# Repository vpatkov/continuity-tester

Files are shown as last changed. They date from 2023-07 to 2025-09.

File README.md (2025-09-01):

# Continuity Tester

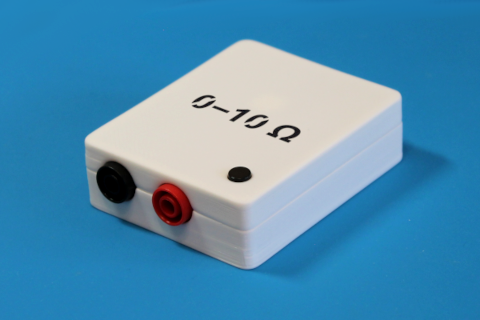
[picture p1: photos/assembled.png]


Ultra low-voltage and fast continuity tester. Digital multimeters are very good
at precise measurements but usually not so good at continuity testing. This
little tester solves the problem.

- **Open terminals voltage is 100 mV, short terminals current is 100 μA.**
  Suitable for in-circuit testing (keep p-n junctions closed) without the
  risk of damaging sensitive components. DMMs usually apply several volts or
  milliamps to the terminals (and not always specified).

- **Resistance-dependent beeper tones with chromatic steps.**
  Allows you to differentiate resistance by ear without moving your viewpoint.
  The range is 0–10 Ω with 1 Ω steps. DMMs usually have a pretty big threshold
  and require you to look at the screen to read the resistance, e.g. if you
  want to catch a bad connection.

- **Detects shorts of 1 ms with an ensured minimal beep duration of 100 ms.**
  Suitable for finding connections by sweeping and brushing without the risk
  of missing a beep. Gold-plated probes are recommended.

- **Auto-hold the minimal resistance.**
  Helps against unstable contacts, e.g. on dirty, oxidized, or lacquered
  boards. The hold resets when the resistance becomes greater than 10 Ω.

- **200 working hours on a single CR2032 cell.**
  Consumes 0.7 mA when on (+0.3 mA when beeping), 0.1 μA when off. After 3
  minutes of inactivity the tester switched off automatically.

- **±30 V input protection.**
  The tester should not be used on a powered circuit, but just in case.
  Also saves against charged capacitors. The input impedance of the tester is
  1 kΩ, so the risk of damaging an accidentally powered circuit under test is
  also low.



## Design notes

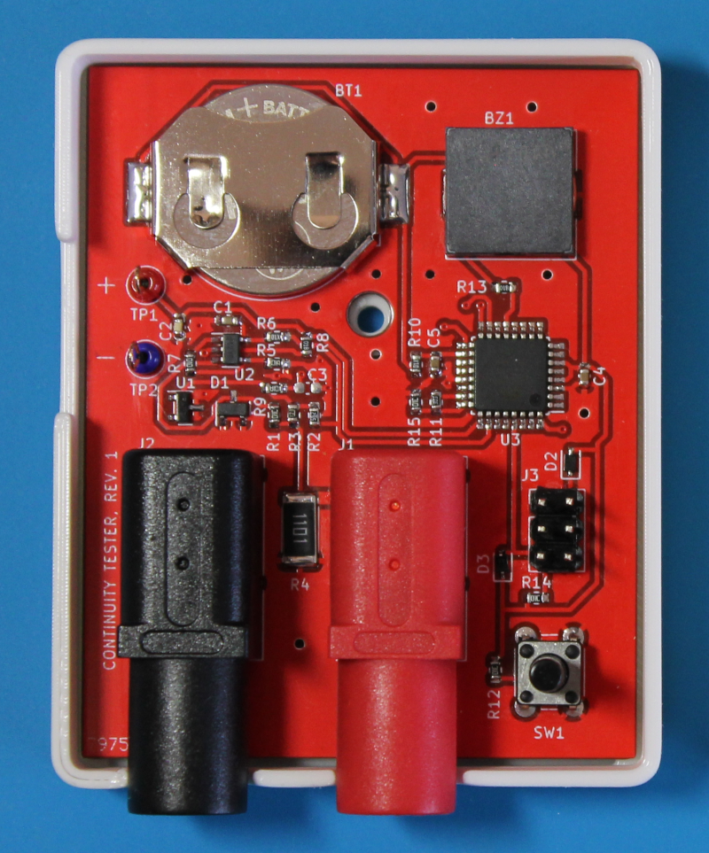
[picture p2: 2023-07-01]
photos/open.png

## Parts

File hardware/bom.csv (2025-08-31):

Reference | Qty | Value | Footprint | Note
BT1 | 1 | CR2032 | Battery:BatteryHolder_MPD_BC2003_1x2032
BZ1 | 1 | PKLCS1212E4001 | Buzzer_Beeper:Buzzer_Murata_PKLCS1212E
C1,C4,C5 | 3 | 100n | Capacitor_SMD:C_0603_1608Metric
C2 | 1 | 1n | Capacitor_SMD:C_0603_1608Metric
D1 | 1 | BAV99 | Package_TO_SOT_SMD:SOT-23
D2 | 1 | BAT54J | Diode_SMD:D_SOD-323F
D3 | 1 | BAS316 | Diode_SMD:D_SOD-323
J1,J2 | 2 | Banana | Connector:Banana_Cliff_FCR7350x_S16N-PC_Horizontal
J3 | 1 | Pin Header Male | Connector_PinHeader_2.54mm:PinHeader_2x03_P2.54mm_Vertical
Q1 | 1 | AO3423 | Package_TO_SOT_SMD:SOT-23
R1,R12,R14 | 3 | 10k | Resistor_SMD:R_0603_1608Metric
R2 | 1 | 6.2k | Resistor_SMD:R_0603_1608Metric
R3 | 1 | 12.4k | Resistor_SMD:R_0603_1608Metric | 1%
R4 | 1 | 1.1k | Resistor_SMD:R_2512_6332Metric | 1% 1W
R5 | 1 | 1k | Resistor_SMD:R_0603_1608Metric | 1%
R6,R10 | 2 | 10 | Resistor_SMD:R_0603_1608Metric
R7 | 1 | 1M | Resistor_SMD:R_0603_1608Metric | 1%
R8,R13 | 2 | 1k | Resistor_SMD:R_0603_1608Metric
R9 | 1 | 100 | Resistor_SMD:R_0603_1608Metric
R11 | 1 | 30k | Resistor_SMD:R_0603_1608Metric | 1%
R15 | 1 | 10k | Resistor_SMD:R_0603_1608Metric | 1%
SW1 | 1 | Tactile Button | Button_Switch_THT:SW_PUSH_6mm | Height 15mm
TP1,TP2 | 2 | TestPoint | TestPoint:TestPoint_Loop_D3.50mm_Drill0.9mm_Beaded
U1 | 1 | TLV431 | Package_TO_SOT_SMD:SOT-23
U2 | 1 | MCP6V61 | Package_TO_SOT_SMD:SOT-23-5
U3 | 1 | ATmega88PA-A | Package_QFP:TQFP-32_7x7mm_P0.8mm

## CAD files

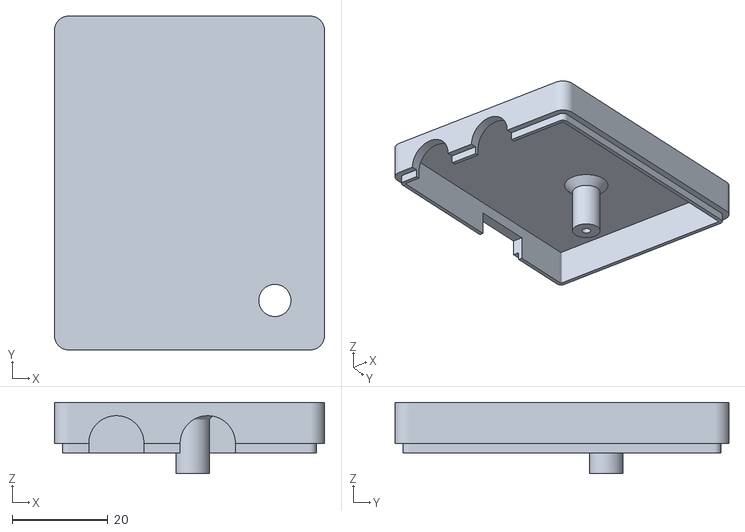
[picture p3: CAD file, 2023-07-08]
case/top.stl
56.3 x 69.6 x 14.8

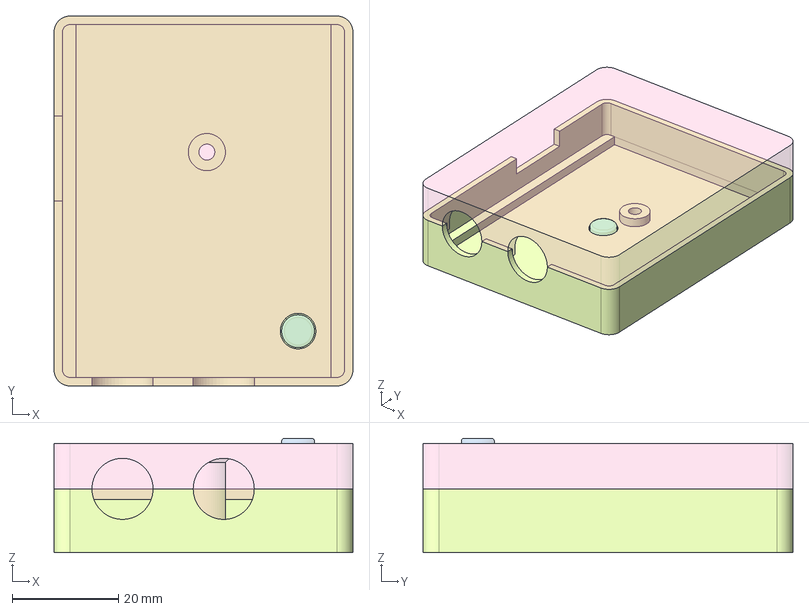
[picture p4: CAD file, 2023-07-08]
case/case.FCStd
56.3 x 69.6 x 21.5 mm
bottom
top
cap

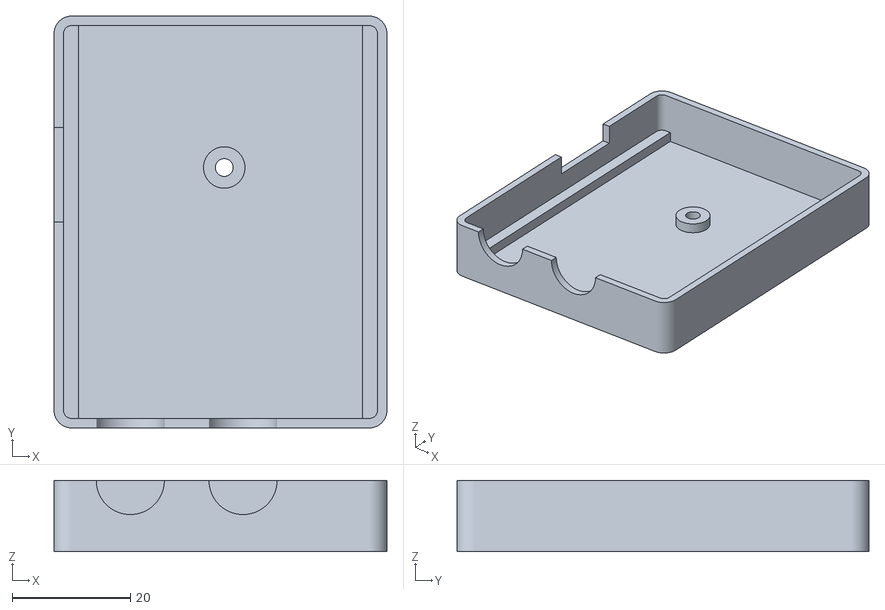
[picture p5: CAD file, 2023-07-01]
case/bottom.stl
56.3 x 69.6 x 12.0

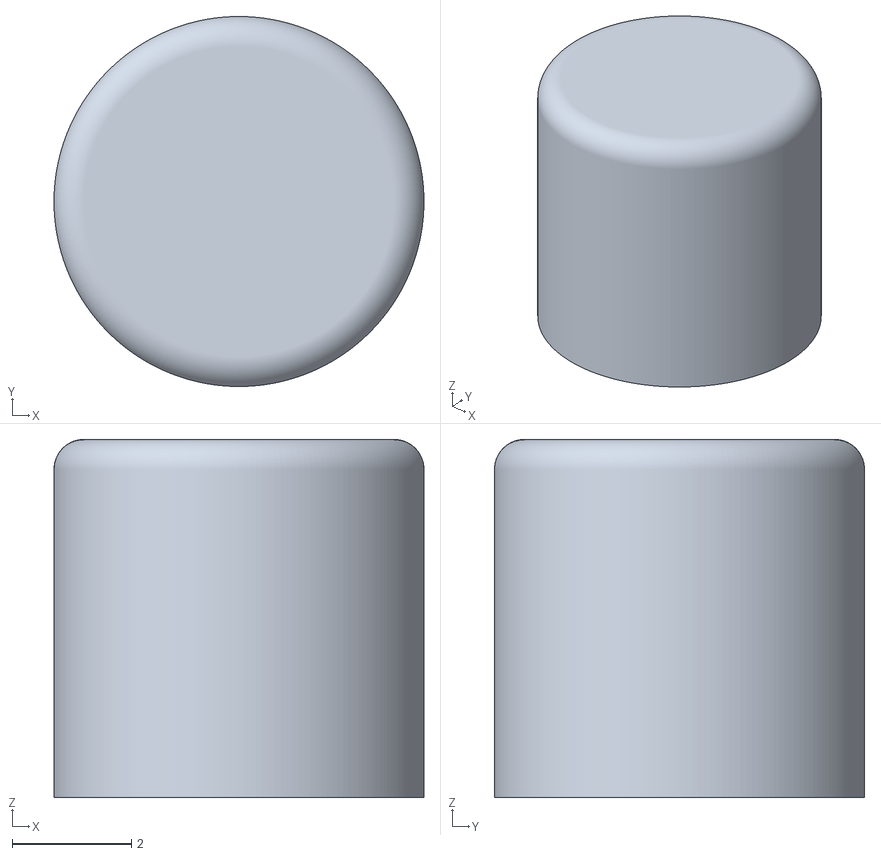
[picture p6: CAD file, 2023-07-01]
case/cap.stl
6.20 x 6.20 x 6.00

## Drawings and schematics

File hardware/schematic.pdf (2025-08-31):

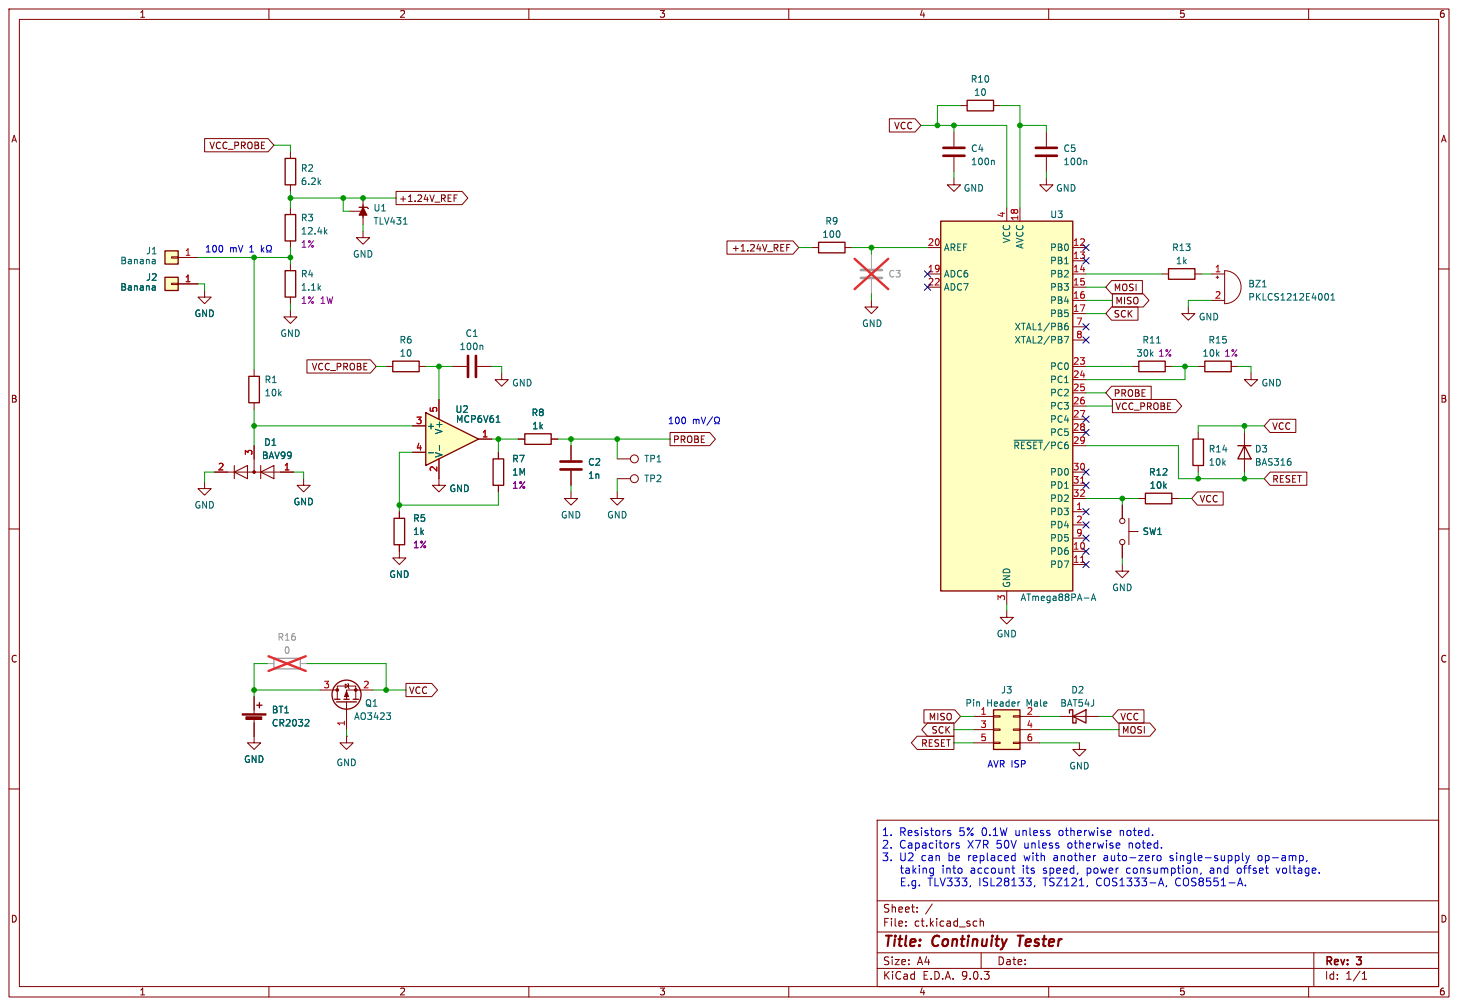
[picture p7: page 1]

Id: 1/1 Title: Continuity Tester File: ct.kicad_sch Sheet: /

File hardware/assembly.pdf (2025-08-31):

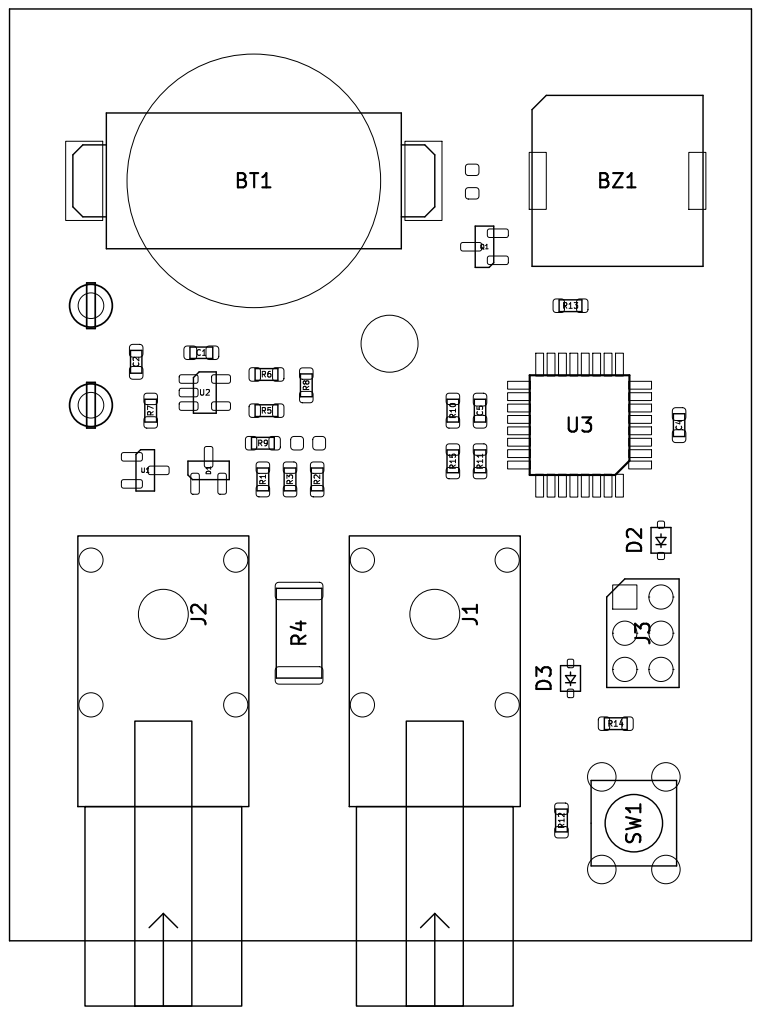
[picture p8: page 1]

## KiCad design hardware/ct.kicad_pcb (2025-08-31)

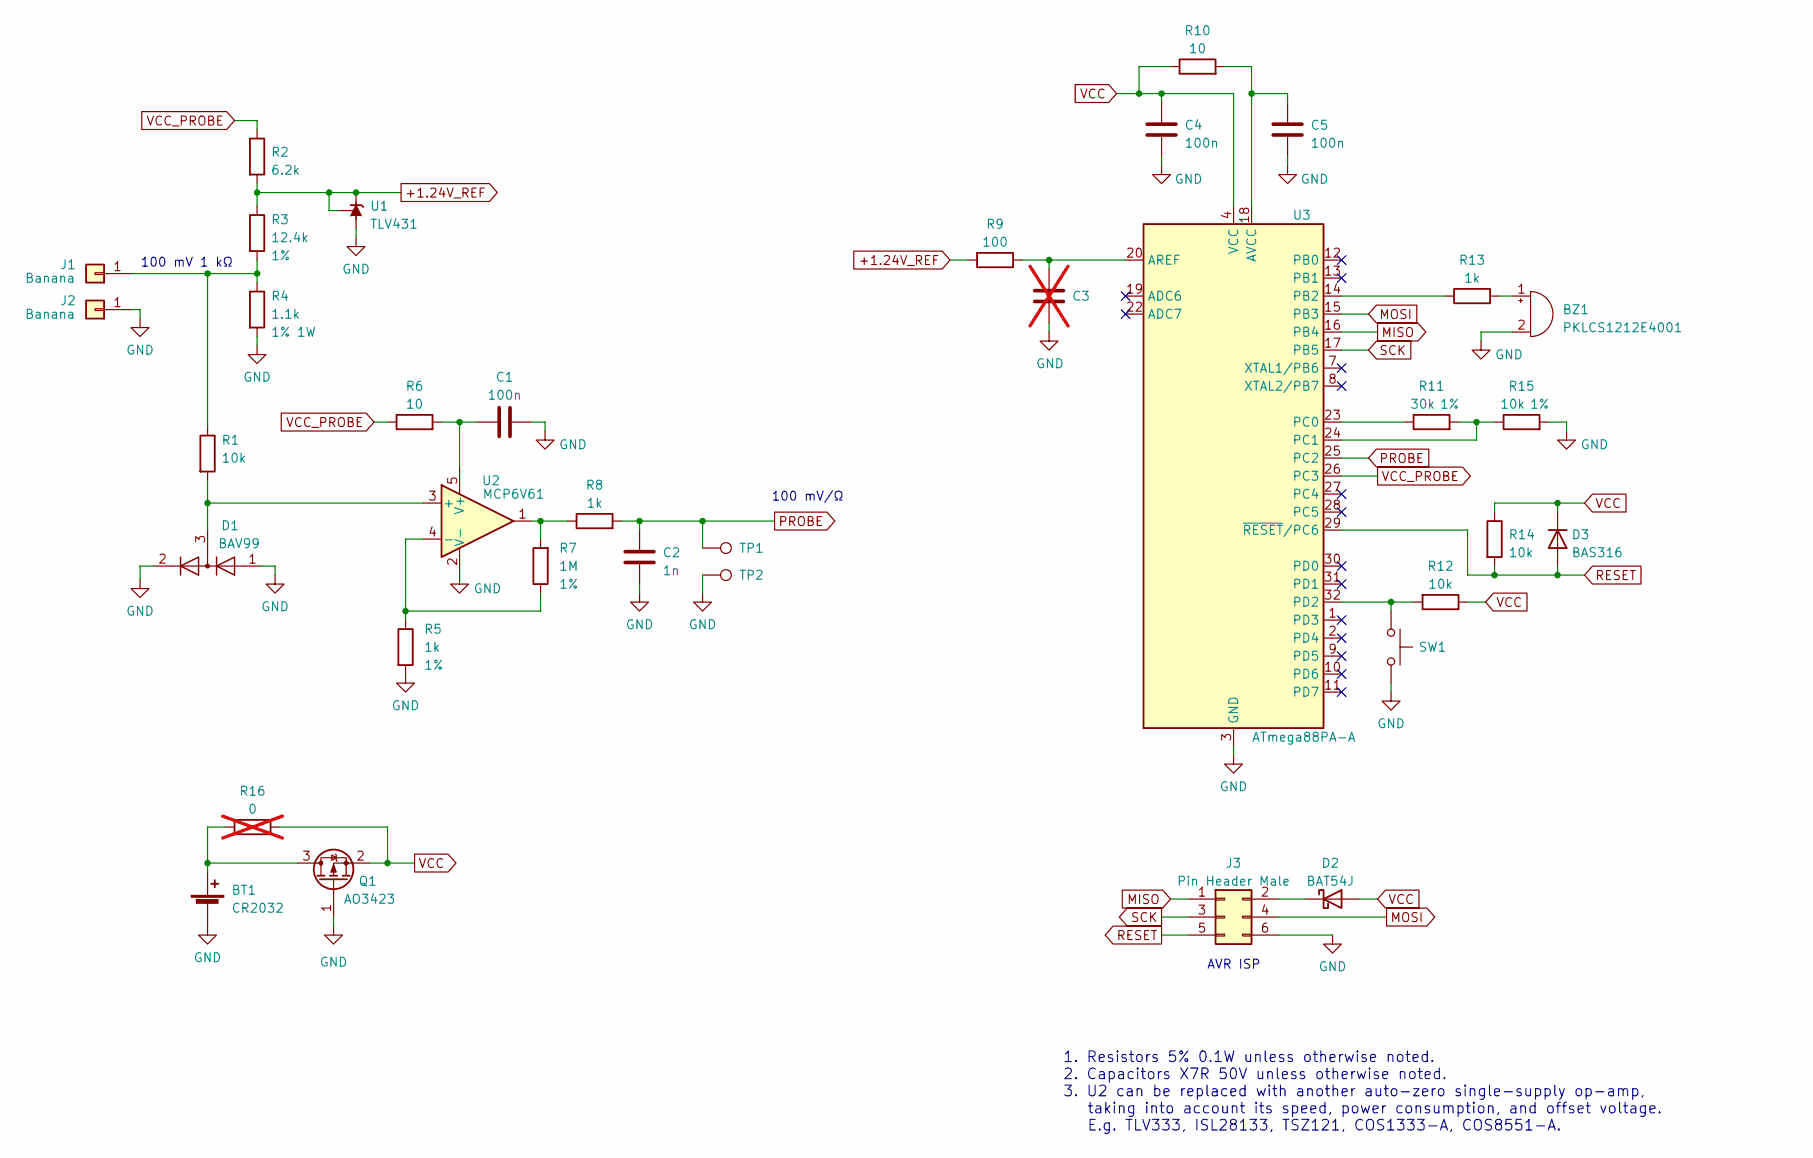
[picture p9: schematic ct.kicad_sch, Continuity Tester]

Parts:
BT1: CR2032; BatteryHolder_MPD_BC2003_1x2032
BZ1: PKLCS1212E4001; Buzzer_Murata_PKLCS1212E
C1, C4, C5: 100n; C_0603_1608Metric
C2: 1n; C_0603_1608Metric
C3: C_0603_1608Metric; not fitted
D1: BAV99; SOT-23
D2: BAT54J; D_SOD-323F
D3: BAS316; D_SOD-323
J1, J2: Banana; Banana_Cliff_FCR7350x_S16N-PC_Horizontal
J3: Pin Header Male; PinHeader_2x03_P2.54mm_Vertical
Q1: AO3423; SOT-23
R1, R12, R14, R15: 10k; R_0603_1608Metric
R2: 6.2k; R_0603_1608Metric
R3: 12.4k; R_0603_1608Metric
R4: 1.1k; R_2512_6332Metric
R5, R8, R13: 1k; R_0603_1608Metric
R6, R10: 10; R_0603_1608Metric
R7: 1M; R_0603_1608Metric
R9: 100; R_0603_1608Metric
R11: 30k; R_0603_1608Metric
R16: 0; R_0603_1608Metric; not fitted
SW1: Tactile Button; SW_PUSH_6mm
TP1, TP2: TestPoint; TestPoint_Loop_D3.50mm_Drill0.9mm_Beaded
U1: TLV431; SOT-23
U2: MCP6V61; SOT-23-5
U3: ATmega88PA-A; TQFP-32_7x7mm_P0.8mm

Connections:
+1.24V_REF: R2.2, R3.1, R9.2, U1.1 (K), U1.2 (REF)
GND: BT1.2 (-), BZ1.2 (+), C1.2, C2.2, C3.2, C4.2, C5.2, D1.1 (K), D1.2 (A), J2.1, J3.6, Q1.1 (G), R4.2, R5.2, R15.2, SW1.2, TP2.1, U1.3 (A), U2.2 (V-), U3.3 (GND), U3.5 (GND), U3.21 (GND)
MISO: J3.1, U3.16 (PB4)
MOSI: J3.4, U3.15 (PB3)
unnamed: BT1.1 (+), Q1.3 (D), R16.1
unnamed: BZ1.1 (-), R13.2
unnamed: D2.1 (K), J3.2
unnamed: J1.1, R1.1, R3.2, R4.1
unnamed: R7.2, R8.1, U2.1
unnamed: D1.3 (K), R1.2, U2.3 (+)
unnamed: R5.1, R7.1, U2.4 (-)
unnamed: C1.1, R6.2, U2.5 (V+)
unnamed: C3.1, R9.1, U3.20 (AREF)
unnamed: C5.1, R10.2, U3.18 (AVCC)
unnamed: R13.1, U3.14 (PB2)
unnamed: R11.1, U3.23 (PC0)
unnamed: R11.2, R15.1, U3.24 (PC1)
unnamed: R12.2, SW1.1, U3.32 (PD2)
PROBE: C2.1, R8.2, TP1.1, U3.25 (PC2)
RESET: D3.2 (A), J3.5, R14.2, U3.29 (~RESET/PC6)
SCK: J3.3, U3.17 (PB5)
VCC: C4.1, D2.2 (A), D3.1 (K), Q1.2 (S), R10.1, R12.1, R14.1, R16.2, U3.4 (VCC), U3.6 (VCC)
VCC_PROBE: R2.1, R6.1, U3.26 (PC3)

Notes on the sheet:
100 mV/Ω
AVR ISP
1. Resistors 5% 0.1W unless otherwise noted. 2. Capacitors X7R 50V unless otherwise noted. 3. U2 can be replaced with another auto-zero single-supply op-amp, taking into account its speed, power consumption, and offset voltage. E.g. TLV333, ISL28133, TSZ121, COS1333-A, COS8551-A.
100 mV 1 kΩ

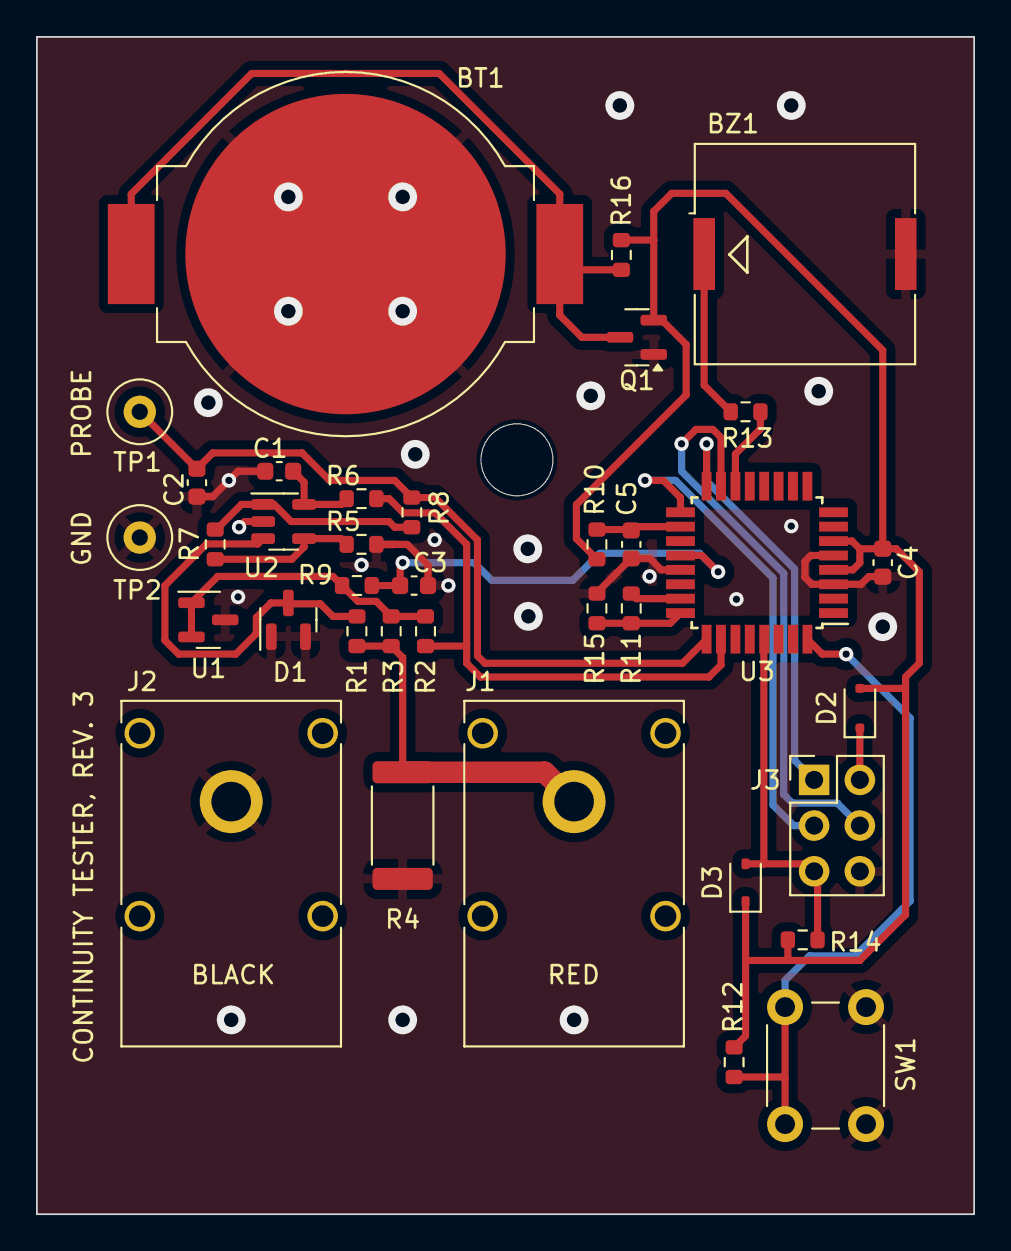
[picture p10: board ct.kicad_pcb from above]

Board: 2 copper layers, 52.1 x 65.4 mm, 36 parts (0 on the bottom side), 23 nets.

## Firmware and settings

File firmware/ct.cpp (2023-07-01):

/* Main program */

#include <stdint.h>
#include <avr/io.h>
#include <avr/pgmspace.h>
#include <avr/sleep.h>
#include "common.hpp"
#include "delay.hpp"
#include "gpio.hpp"
#include "tones.hpp"
#include "volatile.hpp"

/* Peripherals are configured for 1 MHz system clock */
static_assert(F_CPU == 1e6, "");

constexpr Gpio::Pin beeper = Gpio::B2;
constexpr Gpio::Pin vcc_fuel = Gpio::C0;
constexpr Gpio::Pin vcc_probe = Gpio::C3;
constexpr Gpio::Pin button = Gpio::D2;

constexpr Gpio::Pin unused_pins[] = {
	Gpio::B0,
	Gpio::B1,
	Gpio::B3,
	Gpio::B4,
	Gpio::B5,
	Gpio::B6,
	Gpio::B7,
	Gpio::C4,
	Gpio::C5,
	Gpio::D0,
	Gpio::D1,
	Gpio::D3,
	Gpio::D4,
	Gpio::D5,
	Gpio::D6,
	Gpio::D7,
};

constexpr uint8_t fuel_adc_channel = 1;
constexpr uint8_t probe_adc_channel = 2;
constexpr uint8_t iref_adc_channel = 14;

static void beep(uint16_t tone)
{
	if (tone) {
		/* Set T/C1 for 50% PWM on OC1B pin */
		TCCR1A = 1<<COM1B1| 1<<WGM11 | 1<<WGM10;
		TCCR1B = 1<<WGM13 | 1<<WGM12 | 1<<CS10;
		OCR1A = tone;
		OCR1B = tone/2;
	} else {
		/* Stop T/C1 and disconnect OC1B */
		TCCR1A = 0;
		TCCR1B = 0;
	}
}

static void play(const uint16_t *tones)
{
	uint16_t tone;
	while ((tone = pgm_read_word(tones++)) != 0) {
		beep(tone);
		delay_ms(50);
		beep(0);
		delay_ms(50);
	}
}

static uint8_t adc_measure(uint8_t channel)
{
	constexpr uint8_t nr_samples = 64;
	uint16_t acc = 0;

	for (uint8_t i = 0; i < nr_samples; i++) {
		ADMUX = channel & 15;
		ADCSRA = 1<<ADEN | 1<<ADSC | 1<<ADPS1 | 1<<ADPS0;  /* 125 kHz */
		while (ADCSRA & (1<<ADSC))
			memory_barrier();
		acc += ADC;
	}

	return acc/nr_samples/4;
}

static bool self_test()
{
	/* Check internal (1.1 V) vs external (1.24 V) references */
	constexpr uint8_t iref_min = 1.1 * 256/1.24 * 0.9;
	constexpr uint8_t iref_max = 1.1 * 256/1.24 * 1.1;
	uint8_t iref = adc_measure(iref_adc_channel);
	if (iref < iref_min || iref > iref_max)
		return false;

	/* Check the battery voltage */
	constexpr uint8_t fuel_min = 2.7/4 * 256/1.24;
	uint8_t fuel = adc_measure(fuel_adc_channel);
	if (fuel < fuel_min)
		return false;

	return true;
}

static bool power_up()
{
	Gpio::write(vcc_probe, 1);
	Gpio::write(vcc_fuel, 1);
	delay_ms(100);
	bool r = self_test();
	Gpio::write(vcc_fuel, 0);
	while (Gpio::read(button) == 0)
		delay_ms(100);
	return r;
}

EMPTY_INTERRUPT(INT0_vect);

static void power_down()
{
	Gpio::write(vcc_probe, 0);
	while (Gpio::read(button) == 0)
		delay_ms(100);
	EIMSK = 1<<INT0;
	ADCSRA = 0;  /* Disable ADC */
	set_sleep_mode(SLEEP_MODE_PWR_DOWN);
	sleep_mode();
	EIMSK = 0;
}

EMPTY_INTERRUPT(ADC_vect);

static void work()
{
	/* ADC: free running, ~4.8 kHz sample rate (1M/16/13) */
	ADMUX = 1<<ADLAR | (probe_adc_channel & 15);
	ADCSRA = 1<<ADEN | 1<<ADSC | 1<<ADATE | 1<<ADIF | 1<<ADIE | 1<<ADPS2;
	ADCSRB = 0;

	uint16_t inactivity_timer = 0;
	set_sleep_mode(SLEEP_MODE_IDLE);

	for (uint8_t cycle = 0;; cycle++) {
		sleep_mode();

		/* ~38 Hz */
		if (cycle % 128 == 0) {
			if (Gpio::read(button) == 0)
				break;
			if (++inactivity_timer > 180.0 * 1e6/16/13/128)  /* 3 minutes */
				break;
		}

		static uint16_t prev_tone = -1;
		uint16_t tone = pgm_read_word(r_tones + ADCH);
		if (tone < prev_tone || (tone != 0 && prev_tone == 0)) {  /* Auto hold and reset */
			if (tone == 0)
				delay_ms(100);  /* Ensured beep duration */
			beep(tone);
			// if (tone == 0)
			// 	delay_ms(100);  /* Ensured silence duration */
			prev_tone = tone;
			inactivity_timer = 0;
		}
		
	}
}

int main()
{
	/* GPIO init */
	Gpio::write(beeper, 0);
	for (auto p : unused_pins)
		Gpio::pull_up(p);
	
	/* Disable unused peripherals */
	ACSR = 1<<ACD;
	DIDR0 = 0b111111;
	DIDR1 = 0b11;
	PRR = 1<<PRTWI | 1<<PRTIM2 | 1<<PRTIM0 | 1<<PRSPI | 1<<PRUSART0;

	sei();
	
	for (;;) {
		if (power_up()) {
			play(power_up_sound);
			work();
			play(power_down_sound);
			power_down();
		} else {
			play(error_sound);
			power_down();
		}
	}

	return 0;
}

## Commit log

2023-07-02 Add alternatives for U2
    [ct.kicad_sch]
2023-07-04 Add a case sticker
2023-07-08 Minor case improvement
    [case.FCStd, top.stl]
2023-08-07 Change U2 to MCP6V61
    [bom.csv, ct.kicad_pcb, ct.kicad_sch]
2025-08-31 Add reverse polarity protection for battery
    [bom.csv, ct.kicad_pcb, ct.kicad_sch]
2025-08-31 Add bypass to the reverse polarity protection
    [ct.kicad_pcb, ct.kicad_sch]

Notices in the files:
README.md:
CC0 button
